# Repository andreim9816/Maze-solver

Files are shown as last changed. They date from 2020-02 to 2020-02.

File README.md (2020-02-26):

# Maze solver

Maze solver robot that must find its way through a labyrinth. The algorithm monitoring the wall is one of the most popular algorithms for finding a way out of the maze, and is also known as the "Rule of the right hand". If the maze of connections, or if all its walls are connected to each other, then if the robot is inside the maze, backing to one side of the wall during the entire passage through the maze, there is a guaranteed way out of the maze, otherwise the robot would be returned to the entrance of the labyrinth and thereby make the rounds of each path in the maze at least once. The task is to go through the entire robot labyrinth and successfully complete it.

### Hardware / BOM ###
<br>

1. Arduino Uno
1. 2x Breadboard
1. Wires
1. 20cm x 15cm plastic board (the support of the car)
1. 3x 9cm x 20cm cardboard (left,right and top walls of the car)
1. 2x 9cm x 15cm cardboare (front and back walls of the car)
1. 2x DC motor
1. IR receiver
1. L293D driver
1. 3x Ultrasonic sensor (HC-SR04)
1. 1x Ultrasonic sensor holder
1. 2x Resistor (220 ohm)
1. 2x Led (green and blue)
1. 2x Wheel
1. Caster Wheel
1. 4x AAA Battery Holder
1. 4x AAA battery
1. 9V battery

[Click here for the BOM link](https://docs.google.com/spreadsheets/d/1Htry010sDG5Vxl1XxuDkIDsEU6a6pIBbHVVmY9l-o_E/edit#gid=253948986)

<br>

## Photo of the entire project ##
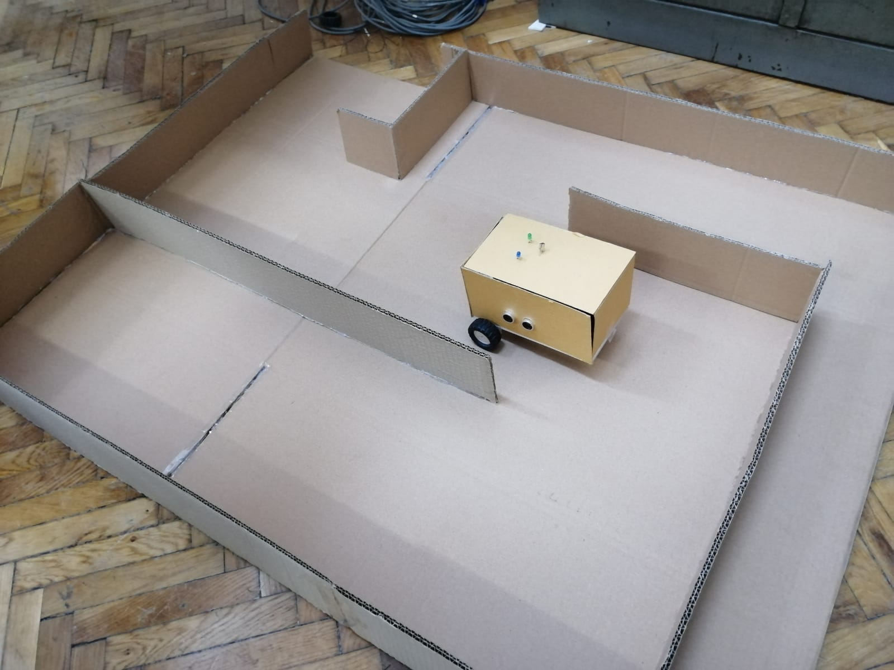
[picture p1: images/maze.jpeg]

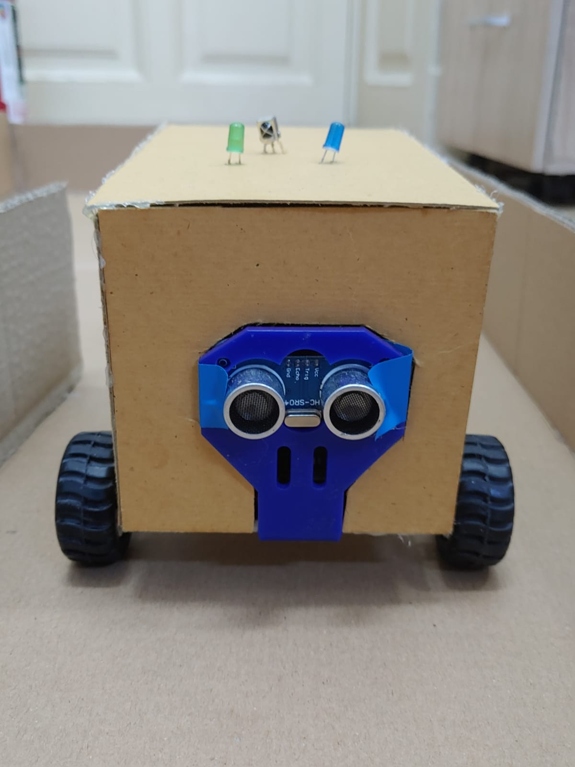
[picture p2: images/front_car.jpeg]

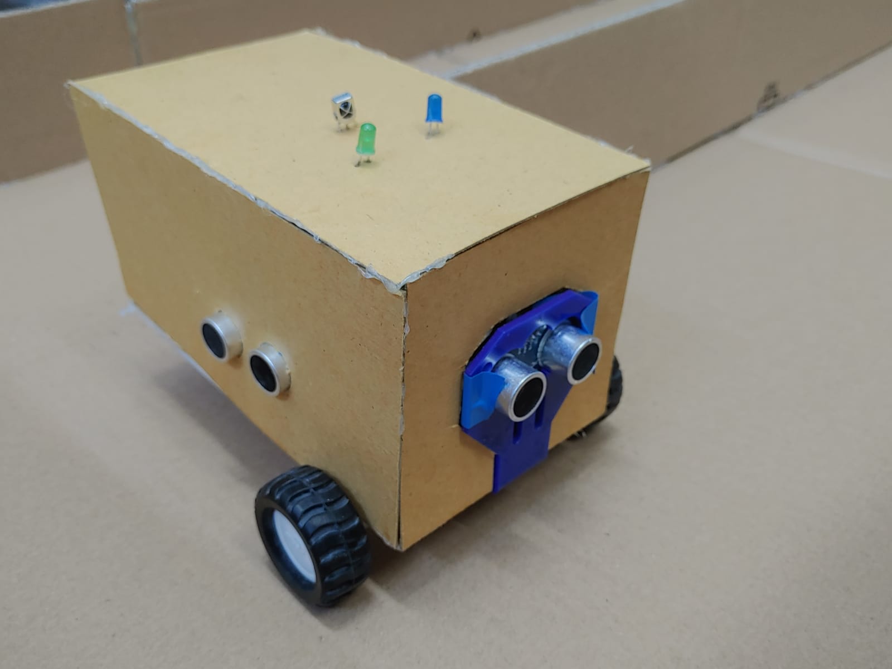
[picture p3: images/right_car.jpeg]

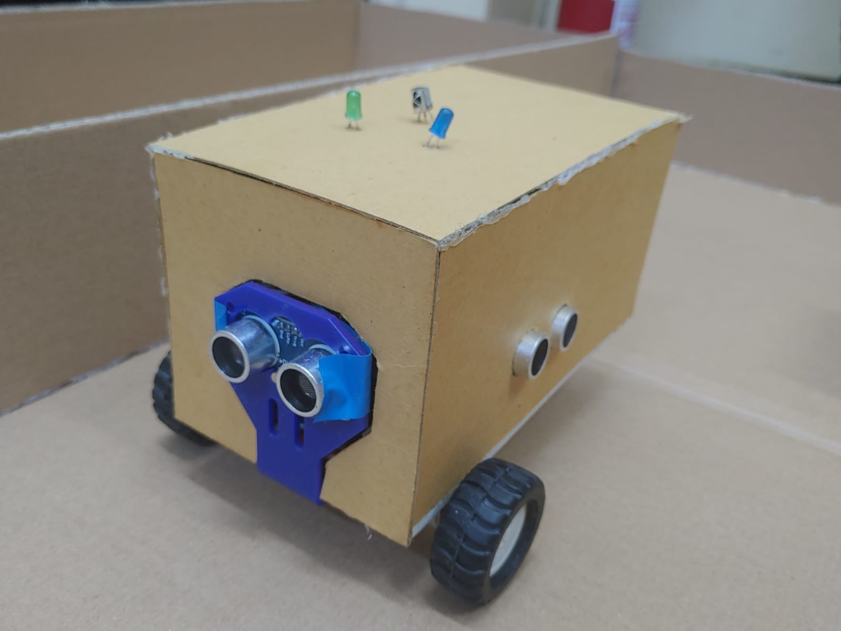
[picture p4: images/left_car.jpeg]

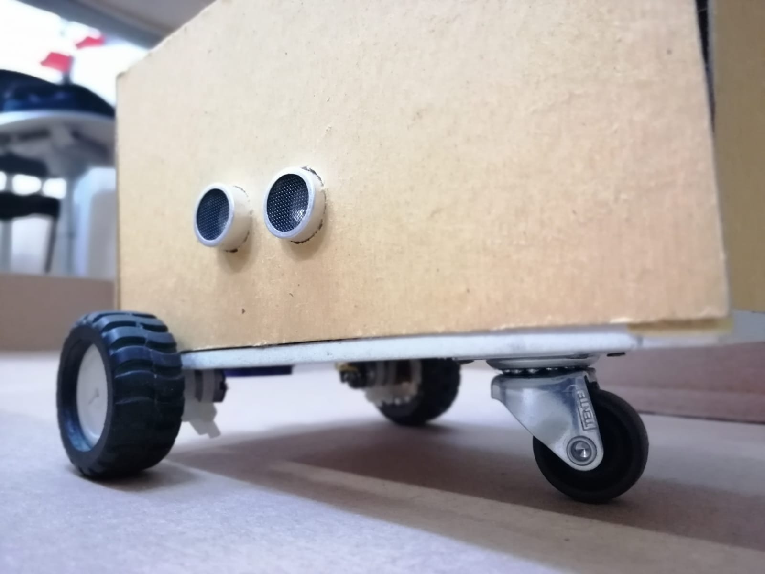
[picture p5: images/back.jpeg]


<br>

## Schematics for the car ##

<br>

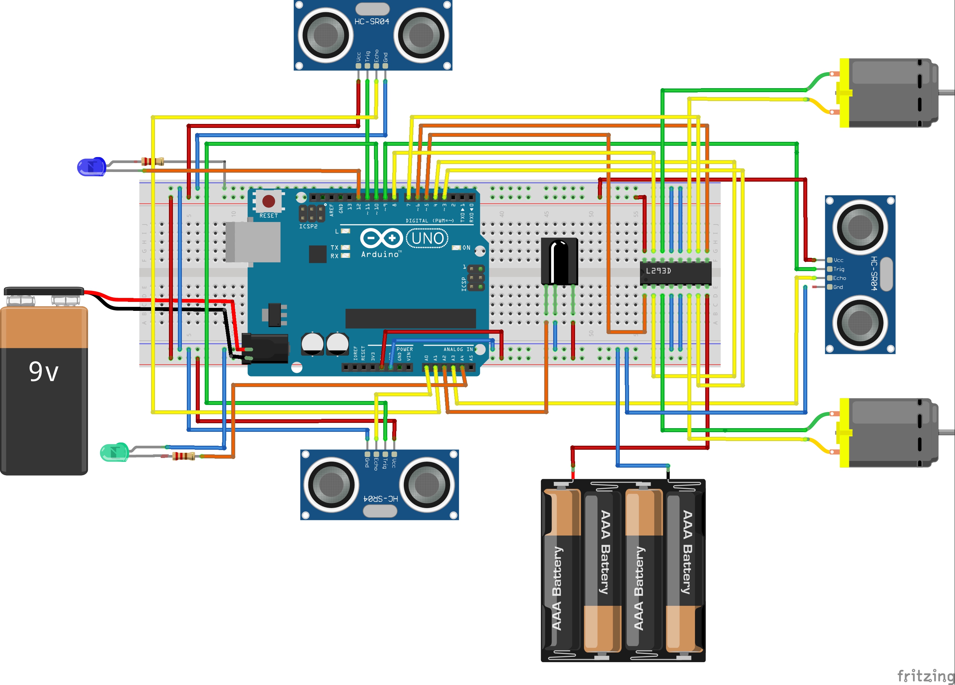
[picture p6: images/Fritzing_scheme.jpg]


<br>

## Demo video ##
[Click here for the demo video](https://youtu.be/VE46upkJfwo)

<br>

## Instructions / features ##

### Turn on / off ###

The motors of the car are turned on/off by the IR remote. To power it, you need to press the **>>|** button, and to stop it, the **>|** button. Once the motors are powered up, the car started to move. 

### Moving through the maze ###

Once the car is turned on, there are 3 main cases in which the car behaves:
<br>
1. There is a new path on the right side of the car. Then, no matter if the car could still go forward or on the left, it chooses to make a 90° rotation to the right and continues to go forward until a new case is met.
1. There is a new path on the left. Here, there are another 2 cases:
   1. The car can still go forward. Then, it chooses to go forward
   1. The car can't go forward. Basically, the only possible way it to make a 90° rotation to the left.
1. The car is blocked (can't go to the left, right or front). In this case, it makes a 180° rotation and starts to go forward.

### Ultrasonic sensors ###

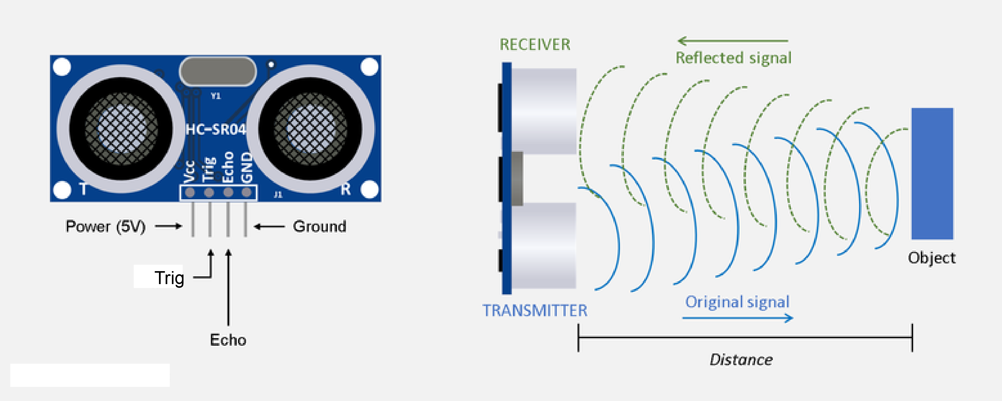
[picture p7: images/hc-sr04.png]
To establish the position of the car in the maze(how much space is on the left, right, or in front of it), we used 3 ultrasonic sensors to measure the distance. We then calculate the distance, using the speed of the sound and the time measured by the sensor. 

### PID control ###

When the car is moving forward, to ensure that is going straight, or if it is too close to one of the walls, to redress it so as the distances between the car and the two walls are almost equal, we used the **PID control**. PID (proportional integral derivative) controllers use a control loop feedback mechanism to control process variables as close to the target or setpoint output as possible. 
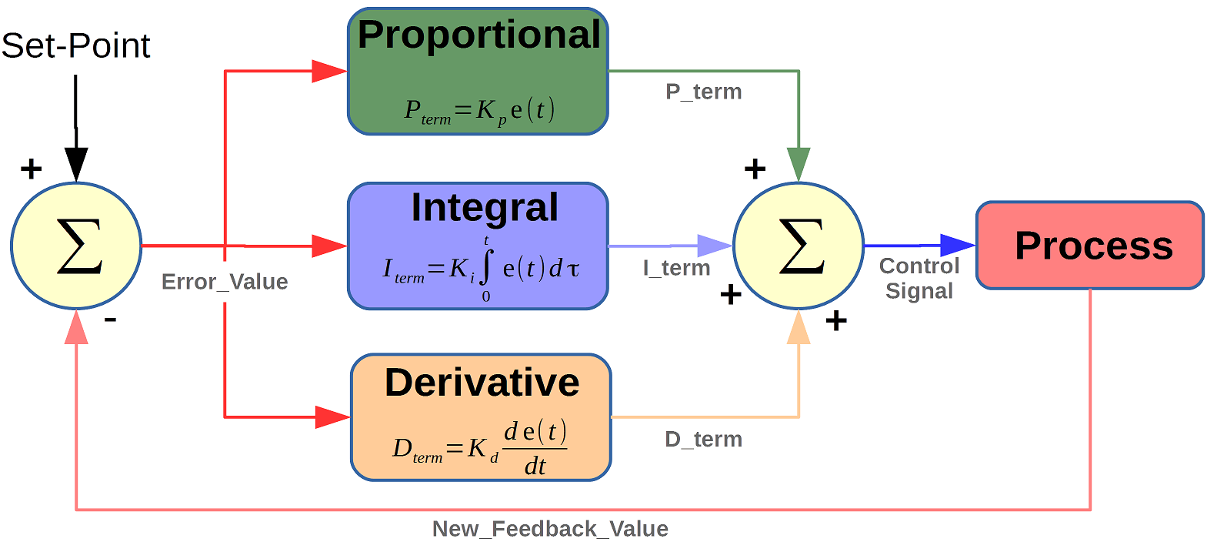
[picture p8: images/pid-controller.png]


### Turning left / right ###

When the car decides to make a 90° rotation, the corresponding led will blink. When the car makes a left-turn, then the green one blinks, otherwise, the blue one blinks.

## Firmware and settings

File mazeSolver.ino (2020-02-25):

#include <IRremote.h>

// pins for the motors

const int leftFw = 3;
const int leftBk = 4;

const int rightFw = 7;
const int rightBk = 8;

const int enablePinRight = 5;
const int enablePinLeft = 6;

// IR remote pin
const int receiverPin = A2;

// pins for the ultrasonics
const int trigPinLeft = 11;
const int echoPinLeft = A1;

const int trigPinRight = 10;
const int echoPinRight = A0;

const int trigPinCenter = 9;
const int echoPinCenter = A3;

// speeds when making a turn
const int speedTurnLeft = 200;
const int speedTurnRight = 200;


// thresholds for the sensors
const int distanceRightThreshold = 25;
const int distanceCenterThreshold = 13;
const int distanceLeftThreshold = 25;

// speeds while going straight forward(for a few seconds, after making a turn)
const int speedLeftForward = 120;
const int speedRightForward = 115;

const int leftSpeed = 130; // default speed of the left DC motor
const int rightSpeed = 125; // default speed of the right DC motor

unsigned long lastTimeTurn = 0; // last time a turn happened
const int noTurn = 2700; // minimum time needed between turns
const int timeRight = 850; // time for turning right
const int timeLeft = 800 ; // time for turning left
const int timeUturn = 1630; // time for 180 turn

// pins for the leds
const int pinBlue = 12;
const int pinGreen = A4;

// variable describing motors state
bool carStop = true; 

// disances for left, right and center sensor
float distanceLeft;
float distanceRight;
float distanceCenter;

// variables for the PID control
float error , lastError, derivative;
const int offset = 8; // distance for the rightWall
int integral;

// constans for the PID control
int turn , Kp = 6, Ki = 0, Kd = 4;
float speedCorrection;

// the spped of each wheel
int leftWheelSpeed , rightWheelSpeed;

// IR remote result
IRrecv irrecv(receiverPin);
decode_results results;

unsigned long keyValue = 0;

void setup()
{
  // motors
  pinMode(leftFw, OUTPUT);
  pinMode(leftBk , OUTPUT);
  pinMode(enablePinLeft , OUTPUT);

  pinMode(rightFw, OUTPUT);
  pinMode(rightFw, OUTPUT);
  pinMode(enablePinRight , OUTPUT);

  // IR
  irrecv.enableIRIn();
  irrecv.blink13(true);

  // ultrasonic sensors
  pinMode(trigPinCenter , OUTPUT); // Sets the trigPin as an Output
  pinMode(echoPinCenter , INPUT);

  pinMode(trigPinLeft , OUTPUT); // Sets the trigPin as an Output
  pinMode(echoPinLeft , INPUT);

  pinMode(trigPinRight , OUTPUT); // Sets the trigPin as an Output
  pinMode(echoPinRight , INPUT);
  
  Serial.begin(9600);
}

void readIR()
{
  /* function that decodes the IR remote signal */
  
  if (irrecv.decode(&results)){
    if (results.value == 0XFFFFFFFF)
      results.value = keyValue;
   
    switch(results.value)
    {   
    case 0xFFC23D:
      stopCar();
      Serial.println(">|"); //stop
      break;
   
    case 0xFF02FD:
      carStop = false;
      Serial.println(">>|"); // start
    break ;
    }
   
    keyValue = results.value;
    irrecv.resume();
    }
}

void stopCar()
{
   /* function that stops the motors of the car(when pressing the remote stop button) */
   
   carStop = true;

   analogWrite(enablePinRight , 0 );
   digitalWrite(rightFw , LOW);
   digitalWrite(rightBk , LOW);

   analogWrite(enablePinLeft , 0);
   digitalWrite(leftFw , LOW);
   digitalWrite(leftBk , LOW);
}

void readSensor(const int trigPin , const int echoPin , float &distance)
{
  /* function that calculates the distance measured by a sensor */
  
  // Clears the trigPin
  digitalWrite(trigPin, LOW);
  delayMicroseconds(2);
  
  // Sets the trigPin on HIGH state for 10 micro seconds
  digitalWrite(trigPin, HIGH);
  delayMicroseconds(10);
  digitalWrite(trigPin, LOW);
  
  // Reads the echoPin, returns the sound wave travel time in microseconds
  float duration = pulseIn(echoPin, HIGH);
  
  // Sound wave reflects from the obstacle, so to calculate the distance we
  // consider half of the distance traveled.
  distance = duration * 0.034 / 2;
}


void forward()
{ 
   /* function that determinates the speed of each wheel, by using the PID control */
   
   // calculates the variables for the PID control  
   error = distanceRight  - offset;
   integral = integral * 2 / 3 + error;
   derivative = error - lastError;
   lastError = error;

   // calculates the speed correction 
   speedCorrection = Kp * error + Ki * integral + Kd * derivative;

   leftWheelSpeed = leftSpeed + speedCorrection;
   rightWheelSpeed = rightSpeed - speedCorrection;

   /*
   Serial.print("distanta = ");
   Serial.print(distanceRight);

   Serial.print(" eroare = ");
   Serial.print(error);
   
   Serial.print(" turn = ");
   Serial.print(turn);
  */

   // sets the new speed of each motor 
   analogWrite(enablePinLeft , leftWheelSpeed);
   digitalWrite(leftFw , HIGH);
   digitalWrite(leftBk , LOW); 
  
   analogWrite(enablePinRight , rightWheelSpeed);
   digitalWrite(rightFw , HIGH);
   digitalWrite(rightBk , LOW);

  /*
   Serial.print(" leftWheelSpeed = ");
   Serial.print(leftWheelSpeed);
   
   Serial.print(" rightWheelSpeed = ");
   Serial.println(rightWheelSpeed);

   Serial.println("FORWARD\n");
  */
}

void turnRight()
{
  /* function that makes the car do a 90° right turn */

  // the new speed of each motor 
  leftWheelSpeed = speedTurnLeft;
  rightWheelSpeed = speedTurnRight;

  // powers the motors, both on the opposite side
  analogWrite(enablePinLeft , leftWheelSpeed);
  digitalWrite(leftFw , HIGH);
  digitalWrite(leftBk , LOW); 
  
  analogWrite(enablePinRight , rightWheelSpeed );
  digitalWrite(rightFw , LOW);
  digitalWrite(rightBk , HIGH);

  unsigned long time = millis();

  // for <<timeRight> ms, the blue led will blink and the car is turning right
  while(millis() - time < timeRight)
  {
    digitalWrite(pinBlue, HIGH);
    readIR();
  }

  // stop the led
  digitalWrite(pinBlue , LOW);
  
  // stop the motors
  analogWrite(enablePinLeft , 0);
  digitalWrite(leftFw , LOW);
  digitalWrite(leftBk , HIGH); 
  
  analogWrite(enablePinRight , 0 );
  digitalWrite(rightFw , HIGH);
  digitalWrite(rightBk , LOW);

  
  lastTimeTurn = millis();
}

void turn180()
{
  /* function that makes the car do a 180° turn */

  // the new speed of each motor 
  leftWheelSpeed = speedTurnLeft;
  rightWheelSpeed = speedTurnRight;

  // powers the dc motors, both on the opposite side
  analogWrite(enablePinLeft , leftWheelSpeed);
  digitalWrite(leftFw , LOW);
  digitalWrite(leftBk , HIGH); 
  
  analogWrite(enablePinRight , rightWheelSpeed );
  digitalWrite(rightFw , HIGH);
  digitalWrite(rightBk , LOW);

  // for <<timeUturn>> ms, the car will make a U-turn
  unsigned long time = millis();
  while(millis() - time < timeUturn)
  {
    readIR();
  }
  
  // stop the motors
  analogWrite(enablePinLeft , 0);
  digitalWrite(leftFw , LOW);
  digitalWrite(leftBk , HIGH); 
  
  analogWrite(enablePinRight , 0 );
  digitalWrite(rightFw , HIGH);
  digitalWrite(rightBk , LOW);
  
  lastTimeTurn = millis();
}

void turnLeft()
{
  /* function that makes the car do a 90° left turn */

  // new speed of each motor
  leftWheelSpeed = speedTurnLeft;
  rightWheelSpeed = speedTurnRight;

  //powers the dc motors, both on the opposite side
  analogWrite(enablePinLeft , leftWheelSpeed);
  digitalWrite(leftFw , LOW);
  digitalWrite(leftBk , HIGH); 
  
  analogWrite(enablePinRight , rightWheelSpeed );
  digitalWrite(rightFw , HIGH);
  digitalWrite(rightBk , LOW);

  unsigned long time = millis();

  // for <<timeLeft>> ms, the green led will blink and the car will turn left
  while(millis() - time < timeLeft)
  {
    digitalWrite(pinGreen, HIGH);
    readIR();
  }

  // stop the green led
  digitalWrite(pinGreen , LOW);

  // stop the motors;
  analogWrite(enablePinLeft , 0);
  digitalWrite(leftFw , LOW);
  digitalWrite(leftBk , HIGH); 
  
  analogWrite(enablePinRight , 0 );
  digitalWrite(rightFw , HIGH);
  digitalWrite(rightBk , LOW);
  
  lastTimeTurn = millis();
}

void maze()
{
  
  if(distanceRight > distanceRightThreshold && millis() - lastTimeTurn > noTurn) // the car goes to the right if it can
        turnRight();
  else if(millis() - lastTimeTurn < noTurn && distanceCenter > distanceCenterThreshold) // if the car just made a turn, then it has to wait until the next turn, so it just goes forward ( if it can)
  {
    analogWrite(enablePinLeft , speedLeftForward);
    digitalWrite(leftFw , HIGH);
    digitalWrite(leftBk , LOW); 
    
    analogWrite(enablePinRight , speedRightForward);
    digitalWrite(rightFw , HIGH);
    digitalWrite(rightBk , LOW);
  }
  else if(distanceCenter > distanceCenterThreshold) // if there is no space on the right, it goes forward, using the PID
        forward();
  else if(distanceLeft > distanceLeftThreshold && millis() - lastTimeTurn > noTurn) // goes to the left if it is the only option
        turnLeft();
  else if(distanceRight < distanceRightThreshold && distanceLeft < distanceLeftThreshold && distanceCenter < distanceCenterThreshold) // if it is blocked, then it makes a U-turn
        turn180();
}

void loop()
{
  // the car works as long as it is not stopped by the remote, when it finishes

  readIR();
  
  if(carStop == false)
  {
    readSensor(trigPinCenter , echoPinCenter , distanceCenter);
    readSensor(trigPinLeft , echoPinLeft , distanceLeft);
    readSensor(trigPinRight , echoPinRight , distanceRight); 
    maze();

    /*
    Serial.print("Left: ");
    Serial.print(distanceLeft);
  
    Serial.print("     Center: ");
    Serial.print(distanceCenter);
  
    Serial.print("      Right: ");
    Serial.println(distanceRight);
    */
  }
  else 
  {
    // the motors are stopped
    analogWrite(enablePinLeft , 0);
    digitalWrite(leftFw , HIGH);
    digitalWrite(leftBk , LOW); 
    
    analogWrite(enablePinRight , 0);
    digitalWrite(rightFw , HIGH);
    digitalWrite(rightBk , LOW);
  }
}
